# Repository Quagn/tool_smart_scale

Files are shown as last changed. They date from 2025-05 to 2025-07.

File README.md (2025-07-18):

# Smart Weight Scale - Cân Thông Minh Đo Trọng Tâm

## Giới thiệu

Dự án thiết kế và xây dựng thiết bị cân thông minh có khả năng:
- Đo trọng lượng chính xác với 6 cảm biến load cell
- Tính toán trọng tâm 2D và 3D
- Hiển thị thông tin qua LCD và Web interface
- Cập nhật firmware OTA (Over-The-Air)

## Tính năng chính

### 1. Đo lường
- **Trọng lượng**: Tổng hợp từ 6 cảm biến load cell
- **Trọng tâm 2D**: Tính toán vị trí X, Y trên mặt phẳng
- **Trọng tâm 3D**: Sử dụng servo để nghiêng và tính toán độ cao Z
- **Hiệu chuẩn**: Tự động lưu và khôi phục từ EEPROM

### 2. Giao diện
- **LCD 16x2**: Hiển thị trọng lượng, trọng tâm, menu
- **Web Interface**: Theo dõi real-time qua WebSocket
- **API RESTful**: Tích hợp với các hệ thống khác

### 3. Điều khiển
- **2 nút bấm**: Đa chức năng (click, double-click, long press)
- **Menu hệ thống**: Điều hướng các chức năng
- **Chế độ OTA**: Cập nhật firmware qua WiFi

## Kiến trúc Hệ thống

### Sơ đồ Tổng quan

```mermaid
graph TB
    subgraph "Hardware Layer"
        HW1["6x Load Cell"]
        HW2["3x HX711 ADC"]
        HW3["LCD 16x2 I2C"]
        HW4["2x Push Button"]
        HW5["1x Servo Motor"]
        HW6["Battery Monitor"]
        HW7["ESP8266 (NodeMCU)"]
    end
    
    subgraph "Driver Layer"
        DRV1["LoadCellArray"]
        DRV2["Display"]
        DRV3["ButtonManager"]
        DRV4["ServoController"]
        DRV5["BatteryMonitor"]
    end
    
    subgraph "Application Layer"
        APP1["StateMachine"]
        APP2["Main Loop"]
        APP3["Event Handlers"]
    end
    
    subgraph "Service Layer"
        SRV1["WebServer"]
        SRV2["WebSocket"]
        SRV3["OTA Service"]
        SRV4["WiFi Manager"]
    end
    
    subgraph "External Interface"
        EXT1["Web Browser"]
        EXT2["Mobile App"]
        EXT3["REST API Clients"]
    end
    
    HW1 --> HW2
    HW2 --> DRV1
    HW3 --> DRV2
    HW4 --> DRV3
    HW5 --> DRV4
    HW6 --> DRV5
    
    DRV1 --> APP2
    DRV2 --> APP2
    DRV3 --> APP3
    DRV4 --> APP2
    DRV5 --> APP2
    
    APP3 --> APP1
    APP1 --> APP2
    
    APP2 --> SRV1
    APP2 --> SRV2
    SRV3 --> HW7
    SRV4 --> HW7
    
    SRV1 --> EXT1
    SRV2 --> EXT1
    SRV1 --> EXT2
    SRV1 --> EXT3
```

## Trình tự Hoạt động Chi tiết

### 1. Quy trình Khởi động (Setup Flow)

```mermaid
flowchart TD
    A[Start] --> B["Initialize Serial (115200 baud)"]
    B --> C[setupHardware]
    
    C --> C1["Init Display - Show Booting..."]
    C1 --> C2["Init Buttons - Set callbacks"]
    C2 --> C3["Init Battery Monitor"]
    C3 --> C4["Init Servo"]
    C4 --> C5["Init State Machine"]
    
    C5 --> D{"Button 1 Pressed?"}
    D -->|Yes| E["Set OTA Mode - Display OTA Mode"]
    D -->|No| F["Normal Mode"]
    
    E --> G[setupNetwork]
    F --> G
    
    G --> G1["Try WiFi Connection (STA Mode)"]
    G1 --> G2{"Connected?"}
    G2 -->|Yes| G3["Display IP Address - Start mDNS"]
    G2 -->|No| G4["Start AP Mode - Display AP IP"]
    
    G3 --> H[setupWebServer]
    G4 --> H
    
    H --> H1["Setup WebSocket (/ws)"]
    H1 --> H2["Setup API Endpoints"]
    H2 --> H3["Setup Web UI (Root page)"]
    H3 --> H4["Start HTTP Server (Port 80)"]
    
    H4 --> I{"OTA Mode?"}
    I -->|Yes| J["setupOTA (Elegant OTA)"]
    I -->|No| K["Init Load Cells"]
    
    J --> L["Enter Main Loop"]
    
    K --> K1{"Load Cells Init OK?"}
    K1 -->|Yes| K2["Send INIT_COMPLETE - Set DISPLAY_WEIGHT"]
    K1 -->|No| K3["Display Error - Send ERROR Event"]
    
    K2 --> L
    K3 --> L
```

#### Chi tiết các bước khởi động:

1. **Khởi tạo Serial**: Baud rate 115200 cho debug
2. **setupHardware()**: 
   - Khởi tạo LCD và hiển thị "Booting..."
   - Cấu hình 2 nút bấm với callback functions
   - Khởi động battery monitor
   - Khởi tạo servo ở vị trí trung tâm
   - Khởi động state machine ở trạng thái BOOT

3. **Kiểm tra chế độ OTA**: Nếu Button 1 được giữ lúc khởi động
4. **setupNetwork()**:
   - Thử kết nối WiFi với credentials đã lưu
   - Nếu thành công: Hiển thị IP, bật mDNS
   - Nếu thất bại: Chuyển sang AP mode

5. **setupWebServer()**:
   - Cấu hình WebSocket endpoint `/ws`
   - Thiết lập các API: `/api/weight`, `/api/center`, `/api/battery`, etc.
   - Tạo trang web đơn giản cho monitoring
   - Khởi động HTTP server trên port 80

6. **Khởi tạo Load Cells** (nếu không phải OTA mode):
   - Khởi tạo 3 HX711 với 6 load cell
   - Load calibration từ EEPROM
   - Kiểm tra kết nối và tính ổn định

### 2. Vòng lặp chính (Main Loop)

```mermaid
flowchart TD
    A["Main Loop Start"] --> B["Update State Machine"]
    B --> C["Update Hardware"]
    
    C --> C1["Update Buttons"]
    C1 --> C2["Update Battery"]
    C2 --> C3{"OTA Mode?"}
    
    C3 -->|No| C4["Update Load Cells"]
    C3 -->|Yes| D["Update WebSocket"]
    
    C4 --> C5["Update Servo"]
    C5 --> C6["Update Display"]
    C6 --> C7["Handle Button Events"]
    
    C7 --> C8{"Current State?"}
    
    C8 -->|IDLE/MEASURING| C9["Display Weight Data"]
    C8 -->|CENTER_GRAVITY_2D/3D| C10["Display Center of Gravity"]
    C8 -->|MENU| C11["Display Menu"]
    C8 -->|Other| D
    
    C9 --> D
    C10 --> D
    C11 --> D
    
    D --> D1["Check WiFi Status"]
    D1 --> D2{"WiFi Connected?"}
    
    D2 -->|Connected & was disconnected| D3["Send NETWORK_CONNECTED event"]
    D2 -->|Disconnected & was connected| D4["Send NETWORK_DISCONNECTED event"]
    D2 -->|No change| D5["Check Battery"]
    
    D3 --> D5
    D4 --> D5
    
    D5 --> D6{"Low Battery?"}
    D6 -->|Yes| D7["Send LOW_BATTERY event"]
    D6 -->|No| A
    
    D7 --> A
```

#### Chi tiết vòng lặp chính:

1. **Update State Machine**: Xử lý events và state transitions
2. **Update Hardware**: 
   - Đọc trạng thái buttons (debouncing, multi-click detection)
   - Đo điện áp pin (moving average filter)
   - Đọc 6 load cell (non-blocking)
   - Cập nhật vị trí servo (smooth movement)
   - Refresh LCD display (rate limited)

3. **Display Logic**: Dựa trên state hiện tại:
   - **IDLE/MEASURING**: Hiển thị tổng trọng lượng + status các cell
   - **CENTER_GRAVITY**: Hiển thị tọa độ X, Y (và Z nếu 3D)
   - **MENU**: Hiển thị menu items và navigation

4. **WebSocket Updates**: Gửi real-time data tới web clients
5. **Network Monitoring**: Tự động reconnect WiFi nếu mất kết nối
6. **Battery Management**: Cảnh báo pin yếu

### 3. Xử lý Sự kiện Nút bấm

```mermaid
flowchart TD
    A["Button Event"] --> B{"Which Button?"}
    
    B -->|Button 1 Click| C["Send BUTTON1_CLICK event"]
    B -->|Button 1 Long Press| D["Send BUTTON1_LONG event"]
    B -->|Button 2 Click| E["Send BUTTON2_CLICK event"]
    B -->|Button 2 Long Press| F["Send BUTTON2_LONG event"]
    B -->|Both Buttons| G["Send BOTH_BUTTONS event"]
    
    C --> C1{"Current State?"}
    C1 -->|IDLE| C2["Send MEASURE_START event"]
    C1 -->|MENU| C3["Navigate Menu (menuNext)"]
    
    D --> D1{"Current State?"}
    D1 -->|IDLE| D2["Force transition to MENU"]
    
    E --> E1{"Current State?"}
    E1 -->|IDLE| E2["Execute Tare - Send TARE_COMPLETE"]
    E1 -->|MENU| E3["Send MENU_SELECT event"]
    
    F --> F1{"Current State?"}
    F1 -->|Not IDLE| F2["Send MENU_EXIT event"]
    
    G --> G1["Emergency Restart (ESP.restart)"]
    
    C2 --> H["Return to Loop"]
    C3 --> H
    D2 --> H
    E2 --> H
    E3 --> H
    F2 --> H
    G1 --> I["System Restart"]
```

#### Chức năng nút bấm chi tiết:

**Button 1 (Primary):**
- **Single Click**: 
  - Ở IDLE: Bắt đầu đo lường
  - Ở MENU: Chuyển đến item tiếp theo
- **Long Press**: Vào menu hệ thống
- **Double Click**: Chuyển chế độ hiển thị (weight ↔ center of gravity)

**Button 2 (Secondary):**
- **Single Click**:
  - Ở IDLE: Thực hiện Tare (zero offset)
  - Ở MENU: Chọn menu item hiện tại
- **Long Press**: Thoát khỏi menu/chế độ hiện tại
- **Double Click**: Hiển thị thông tin hệ thống

**Both Buttons**: Emergency restart

### 4. State Machine

```mermaid
stateDiagram-v2
    [*] --> BOOT : System Start
    
    BOOT --> OTA_MODE : Button 1 held at boot
    BOOT --> INIT : Normal boot
    
    OTA_MODE --> [*] : OTA Update Complete
    
    INIT --> IDLE : INIT_COMPLETE event
    INIT --> ERROR : Initialization failed
    
    IDLE --> MEASURING : MEASURE_START / Button 1 click
    IDLE --> MENU : BUTTON1_LONG
    IDLE --> IDLE : TARE_COMPLETE / Button 2 click
    IDLE --> LOW_BATTERY : Low battery detected
    IDLE --> ERROR : System error
    
    MEASURING --> IDLE : MEASURE_COMPLETE / Timeout
    MEASURING --> IDLE : BUTTON2_LONG (exit)
    MEASURING --> CENTER_GRAVITY_2D : User selection
    
    CENTER_GRAVITY_2D --> CENTER_GRAVITY_3D : 3D measurement request
    CENTER_GRAVITY_2D --> IDLE : BUTTON2_LONG (exit)
    
    CENTER_GRAVITY_3D --> CENTER_GRAVITY_2D : Measurement complete
    CENTER_GRAVITY_3D --> IDLE : BUTTON2_LONG (exit)
    
    MENU --> IDLE : MENU_EXIT / BUTTON2_LONG
    MENU --> CALIBRATION : Menu selection (Calibrate)
    MENU --> TARE : Menu selection (Tare)
    MENU --> NETWORK_CONFIG : Menu selection (Network)
    
    CALIBRATION --> IDLE : Calibration complete
    CALIBRATION --> IDLE : BUTTON2_LONG (cancel)
    
    TARE --> IDLE : TARE_COMPLETE
    
    NETWORK_CONFIG --> IDLE : Configuration complete
    NETWORK_CONFIG --> IDLE : BUTTON2_LONG (cancel)
    
    ERROR --> IDLE : BUTTON1_CLICK / BUTTON2_CLICK (acknowledge)
    
    LOW_BATTERY --> IDLE : Battery level restored
    LOW_BATTERY --> [*] : Auto shutdown
```

#### Mô tả các trạng thái:

- **BOOT**: Khởi động hệ thống
- **OTA_MODE**: Chế độ cập nhật firmware
- **INIT**: Khởi tạo phần cứng
- **IDLE**: Trạng thái chờ, hiển thị trọng lượng
- **MEASURING**: Đang đo lường chính xác
- **CENTER_GRAVITY_2D**: Hiển thị trọng tâm 2D
- **CENTER_GRAVITY_3D**: Đo trọng tâm 3D (với servo)
- **MENU**: Hiển thị menu hệ thống
- **CALIBRATION**: Hiệu chuẩn cảm biến
- **TARE**: Thực hiện cân bằng không
- **NETWORK_CONFIG**: Cấu hình WiFi
- **ERROR**: Trạng thái lỗi
- **LOW_BATTERY**: Cảnh báo pin yếu

## Phần cứng

### Linh kiện chính
- **MCU**: ESP8266 (NodeMCU v2)
- **Cảm biến**: 6x Load cell + 3x HX711 (dual channel)
- **Hiển thị**: LCD 16x2 I2C
- **Cơ khí**: 1x Servo (cho đo 3D)
- **Nguồn**: Pin Li-ion với mạch giám sát điện áp

### Sơ đồ kết nối
```
ESP8266 GPIO    Thiết bị
D6 (GPIO12) --> HX711_1 DOUT
D7 (GPIO13) --> HX711_1 SCK
D5 (GPIO14) --> HX711_2 DOUT
D2 (GPIO4)  --> HX711_2 SCK
D1 (GPIO5)  --> HX711_3 DOUT
D0 (GPIO16) --> HX711_3 SCK
D4 (GPIO2)  --> LCD SDA (I2C)
D3 (GPIO0)  --> LCD SCL (I2C)
D8 (GPIO15) --> Button 1
RX (GPIO3)  --> Button 2
TX (GPIO1)  --> Servo
A0         --> Battery voltage (với voltage divider)
```

## Phần mềm

### Cấu trúc thư mục
```
src/
├── main.cpp           # Chương trình chính
├── config/            # File cấu hình
│   ├── PinConfig.h
│   ├── SystemConfig.h
│   └── WebConfig.h
├── drivers/           # Driver phần cứng
│   ├── LoadCellArray.*
│   ├── Display.*
│   ├── ButtonManager.*
│   ├── ServoController.*
│   └── BatteryMonitor.*
├── services/          # Dịch vụ hệ thống
│   └── ...
├── app/              # Logic ứng dụng
│   └── StateMachine.*
└── utils/            # Tiện ích
    └── ...
```

## Cài đặt và Sử dụng

### 1. Yêu cầu
- PlatformIO IDE (VSCode extension recommended)
- ESP8266 board package
- Các thư viện (tự động cài qua PlatformIO):
  - HX711_ADC
  - LiquidCrystal_I2C
  - ESPAsyncWebServer
  - AsyncElegantOTA
  - ArduinoJson

### 2. Cấu hình
1. Sửa WiFi credentials trong `src/config/WebConfig.h`
2. Điều chỉnh vị trí cảm biến trong `src/config/SystemConfig.h`
3. Kiểm tra pin configuration trong `src/config/PinConfig.h`

### 3. Biên dịch và nạp
```bash
# Build
pio run

# Upload qua USB
pio run --target upload

# Upload OTA (sau lần đầu)
pio run --target upload --upload-port smartscale.local
```

### 4. Sử dụng

#### Khởi động thường:
1. Bật nguồn → Hệ thống tự động kết nối WiFi
2. LCD hiển thị trọng lượng
3. Truy cập web: http://smartscale.local

#### Chế độ OTA:
1. Giữ Button 1 khi khởi động
2. Kết nối WiFi AP: "SmartScale_AP" 
3. Truy cập: http://192.168.4.1/update
4. Upload file firmware.bin

#### Điều khiển nút bấm:
- **Button 1**: Click = Đo | Long = Menu
- **Button 2**: Click = Tare | Long = Thoát
- **Both**: Khởi động lại

## API Endpoints

| Method | Endpoint | Mô tả |
|---|---|---|
| GET | /api/weight | Lấy trọng lượng hiện tại |
| GET | /api/center | Lấy tọa độ trọng tâm |
| GET | /api/battery | Trạng thái pin |
| POST | /api/tare | Thực hiện tare |
| POST | /api/calibrate | Bắt đầu hiệu chuẩn |
| POST | /api/restart | Khởi động lại |

## WebSocket

Kết nối: `ws://smartscale.local/ws`

Dữ liệu (JSON):
```json
{
  "weight": 1234.5,
  "battery": 85,
  "centerX": 10.2,
  "centerY": -5.8
}
```

## Thuật toán Tính Toán

### Trọng tâm 2D
```
X = Σ(Wi × Xi) / ΣWi
Y = Σ(Wi × Yi) / ΣWi

Trong đó:
- Wi: Trọng lượng tại cảm biến i
- Xi, Yi: Tọa độ cảm biến i (mm)
```

### Vị trí 6 cảm biến (bố trí hình tròn, bán kính 150mm):
- LoadCell 0: 0° → (150, 0)
- LoadCell 1: 60° → (75, 129.9)
- LoadCell 2: 120° → (-75, 129.9)
- LoadCell 3: 180° → (-150, 0)
- LoadCell 4: 240° → (-75, -129.9)
- LoadCell 5: 300° → (75, -129.9)

### Trọng tâm 3D
1. Đo ở vị trí nằm ngang → Tính X₀, Y₀
2. Nghiêng cân α° bằng servo → Đo lại → Tính X₁, Y₁
3. Tính Z: `Z = (X₁ - X₀) / tan(α)`

## Hiệu chuẩn

### Quy trình tự động:
1. Vào menu Calibration
2. Đặt cân về 0 → Nhấn Tare
3. Đặt quả cân chuẩn lên từng vị trí
4. Nhập khối lượng chuẩn
5. Hệ thống tự động tính toán và lưu vào EEPROM

### Hiệu chuẩn thủ công qua Web API:
```bash
# Tare all cells
curl -X POST http://smartscale.local/api/tare

# Calibrate specific cell
curl -X POST http://smartscale.local/api/calibrate \
  -d '{"cell": 0, "weight": 1000}' \
  -H "Content-Type: application/json"
```

## Khắc phục sự cố

| Vấn đề | Triệu chứng | Giải pháp |
|---|---|---|
| Không kết nối WiFi | LCD hiển thị AP mode | Kiểm tra SSID/Password, reset về AP mode |
| Load cell không ổn định | Số liệu nhảy liên tục | Kiểm tra kết nối, thực hiện tare, kiểm tra nhiễu |
| LCD không hiển thị | Màn hình trống | Kiểm tra I2C address (mặc định 0x27), kết nối SDA/SCL |
| OTA thất bại | Upload bị lỗi | Kiểm tra dung lượng flash còn trống, network stability |
| Servo không hoạt động | Không nghiêng khi đo 3D | Kiểm tra nguồn servo, kết nối PWM |
| Pin cạn nhanh | Cảnh báo low battery | Kiểm tra voltage divider, tối ưu power management |

## Monitoring và Debug

### Serial Monitor (115200 baud):
```
=== Smart Weight Scale ===
Firmware Version: 1.0.0
Display initialized
ButtonManager initialized
Battery: 4.12V (98%)
LoadCell Array initialized
WiFi connected! IP: 192.168.1.100
Web server started
State transition: BOOT -> IDLE
```

### Web Debug Interface:
- Truy cập: `http://smartscale.local/debug`
- Hiển thị raw data từ tất cả sensors
- Log events và state transitions
- Performance metrics

## Đóng góp

Mọi đóng góp đều được chào đón! Vui lòng:
1. Fork repository
2. Tạo branch mới cho tính năng
3. Commit và push
4. Tạo Pull Request

### Coding Standards:
- Sử dụng camelCase cho variables/functions
- PascalCase cho classes
- UPPER_CASE cho constants
- Comment code bằng tiếng Việt hoặc tiếng Anh
- Follow Arduino coding style

## License

MIT License - Xem file LICENSE để biết thêm chi tiết.

## Changelog

### v1.0.0 (2024-07-16)
- Initial release
- Basic weight measurement
- 2D center of gravity calculation
- Web interface with WebSocket
- OTA update support

### Planned Features:
- [ ] 3D center of gravity với servo
- [ ] Data logging to SPIFFS/SD card
- [ ] Mobile app (React Native)
- [ ] Cloud integration (MQTT/HTTP)
- [ ] Multiple user profiles
- [ ] Advanced calibration wizard

## Tác giả

[Your Name] - [your.email@example.com]

## Lời cảm ơn

- Thư viện HX711 của bogde
- ESPAsyncWebServer của me-no-dev
- AsyncElegantOTA của ayushsharma82
- Cộng đồng Arduino và ESP8266

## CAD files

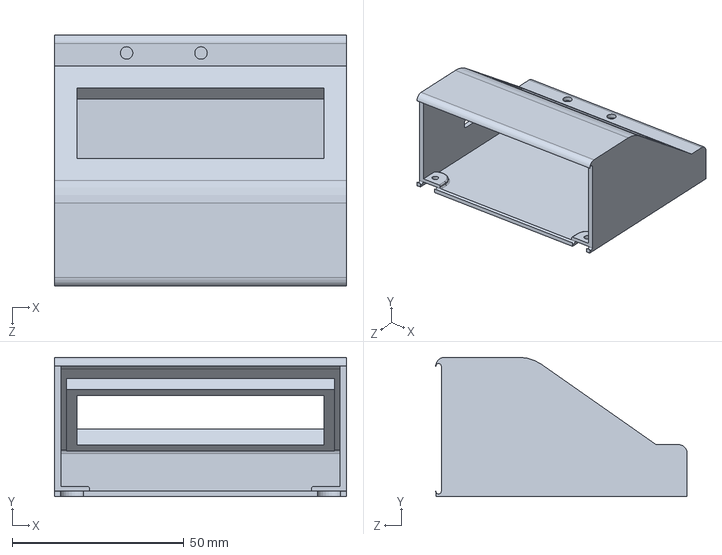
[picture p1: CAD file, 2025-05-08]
hardware/Hop_mach_dieu_khien.SLDPRT
85.0 x 40.6 x 73.2 mm

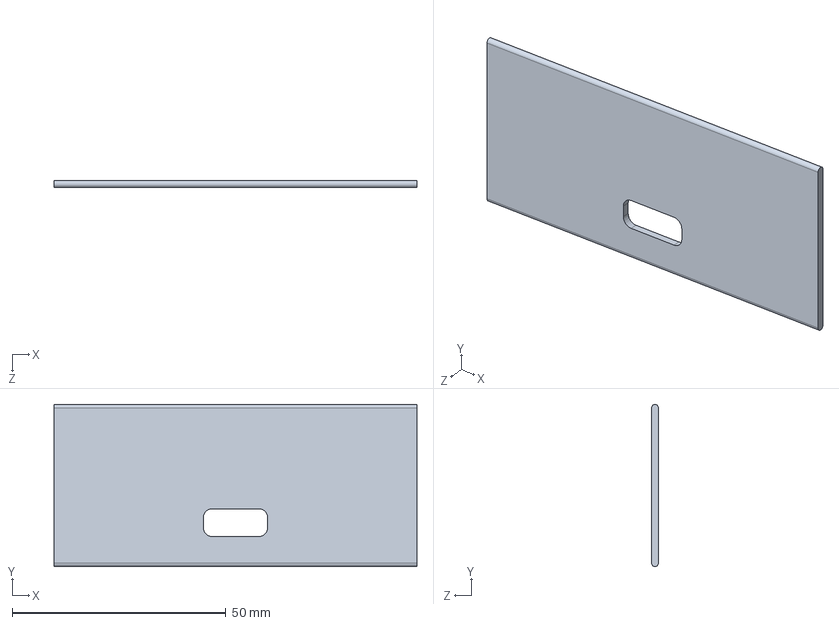
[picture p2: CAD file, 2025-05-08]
hardware/Hop_mach_dieu_khien_nap.SLDPRT
85.0 x 38.0 x 1.60 mm

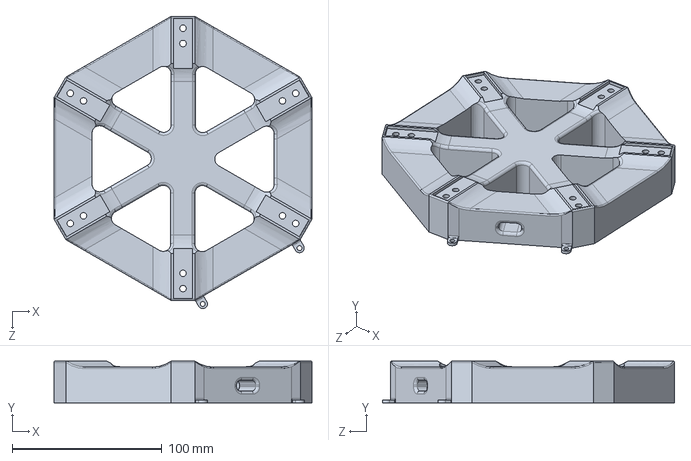
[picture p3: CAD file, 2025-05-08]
hardware/De_Giu.SLDPRT
172.5 x 28.0 x 195.5 mm

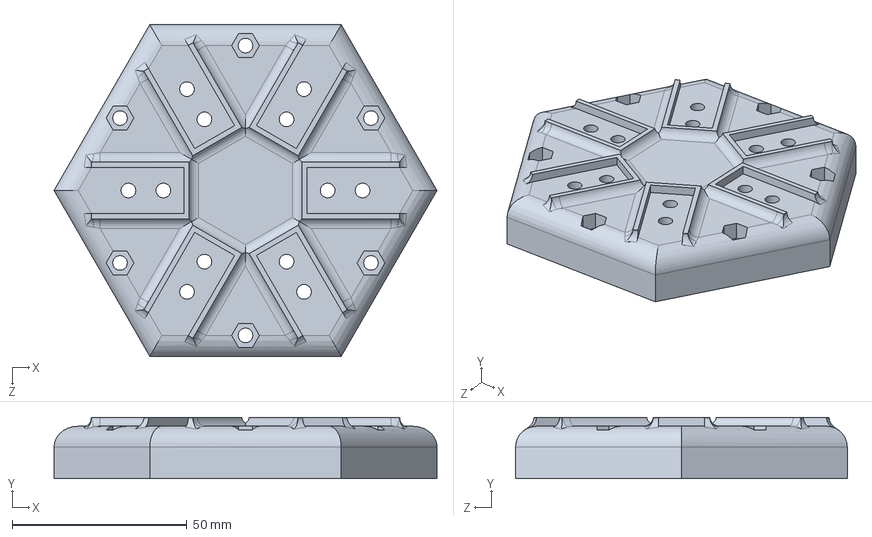
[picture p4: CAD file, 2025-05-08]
hardware/De_tren.SLDPRT
109.7 x 17.5 x 95.0 mm

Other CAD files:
hardware/De_Giu.STL
hardware/De_tren.STL
hardware/Hop_mach_dieu_khien.STL
hardware/Hop_mach_dieu_khien_nap.STL

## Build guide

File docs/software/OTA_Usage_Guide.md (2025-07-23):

# OTA (Over-The-Air) Update Guide

## Overview

The Smart Weight Scale supports wireless firmware updates through OTA (Over-The-Air) functionality. This guide explains how to use this feature.

## How OTA Works

The OTA system in the Smart Weight Scale works as follows:

1. When triggered, the device will first attempt to connect to a known WiFi network (STA mode) for 20 seconds
2. If connection fails, it will create its own WiFi access point (AP mode)
3. The user connects to the device's web interface to upload new firmware
4. After successful update, the device will automatically restart with the new firmware

## Activating OTA Mode

OTA mode can be activated by:

1. Holding the designated button for 5 seconds (BUTTON_OTA_HOLD_TIME)
2. Calling the `ota_start()` function from your code

## Connecting to OTA

### If device connects to your WiFi (STA mode):

1. The device will connect to the configured WiFi network (WIFI_STA_SSID)
2. Look for the device's IP address in your router's connected devices list or in the serial monitor
3. Open a web browser and navigate to: `http://<device-ip>/update`

### If device creates its own WiFi (AP mode):

1. Connect your computer or mobile device to the WiFi network named `SmartScale_OTA`
2. Password: `ota123456`
3. Open a web browser and navigate to: `http://192.168.4.1/update`

## Uploading Firmware

1. In the web interface, click "Choose File" to select your compiled firmware (.bin file)
2. Click "Update" to begin the upload process
3. Wait for the upload to complete (do not disconnect during this process)
4. The device will automatically restart with the new firmware

## Timeout

The OTA mode will automatically exit after 5 minutes (OTA_TIMEOUT_MS) if no update is performed.

## Code Example

```cpp
// Example of triggering OTA mode from your code
void enterOtaMode() {
    // Save any important data before entering OTA mode
    saveSettings();
  
    // Start OTA mode
    ota_start();
  
    // Main loop during OTA mode
    while (true) {
        ota_handle();  // Must be called regularly to handle OTA operations
        delay(10);
    }
}
```

## Customizing OTA Settings

You can customize OTA settings in the following files:

1. `src/config/peripheral_config.h` - WiFi credentials, timeout settings
2. `src/config/web_config.h` - Web server configuration
3. `src/service/ota/ota_handle.h` - OTA function declarations

## Troubleshooting

1. **Cannot connect to device in AP mode**

   - Make sure you're connecting to the correct WiFi network (SmartScale_OTA)
   - Try restarting the device and activating OTA mode again
2. **Upload fails**

   - Ensure you're uploading a valid firmware file (.bin)
   - Check that the file size is not too large for the device
   - Try reconnecting to the WiFi network and uploading again
3. **Device not responding after update**

   - If the device doesn't restart properly after an update, try manually resetting it
   - If issues persist, you may need to use serial programming to restore firmware

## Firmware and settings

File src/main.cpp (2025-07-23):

/*
Auth: Quang Minh
Date: 18/07/2025
*/
//----------------------------------------------------------------------------------// INCLUDES
#include <Arduino.h>                                                        // Arduino core library

#include "config/peripheral_config.h"                                       // Config peripheral
#include "config/service_config.h"                                          // Config service
#include "config/sys_core_config.h"                                         // Config system core
#include "config/sys_app_config.h"                                          // Config system app

#include "peripheral/int/init.h"                                            // Init peripheral
#include "peripheral/ext/button/button.h"                                   // Button
#include "peripheral/ext/battery/battery.h"                                 // Battery
#include "peripheral/ext/servo/servo.h"                                     // Servo

#include "service/power_manager.h"                                          // Power manager
#include "service/wifi_handle.h"                                            // Wifi manager
#include "service/ota/ota_handle.h"                                         // OTA handler

#include "application/event_handle.h"                                       // Event handler
#include "application/state_machine.h"                                      // State machine

//----------------------------------------------------------------------------------// Global variables


//----------------------------------------------------------------------------------// TypeDef
button_t button1;
button_t button2;
servo_t servo;
battery_t battery;

//----------------------------------------------------------------------------------// SETUP
void setup() {   
    power_init();                                                           // Internal peripherals init
    GPIO_Init();   
    I2C_Init();
    UART_Init();
    // ADC_Init();
    // PWM_Init();
    Serial.println("Internal peripherals initialized");

    button_init(&button1, BUTTON_1_PIN, BUTTON_ACTIVE_LOW);                 // External peripherals init
    button_init(&button2, BUTTON_2_PIN, BUTTON_ACTIVE_LOW);
    battery_init(&battery, BATTERY_ADC_PIN);
    servo_init(&servo, SERVO_PIN);
    Serial.println("External peripherals initialized");

    Wifi_Init();
    
    Serial.println("Checking if we should enter OTA mode...");
    // Check if we should enter OTA mode
    //if (button_check_ota_mode_entry(&button1, BUTTON_OTA_HOLD_TIME)) 
    if (true) 
    {
        ota_init();
        ota_start();
        ota_loop();
    } else {
        // Only initialize WiFi in normal mode
        Serial.println("Smart Weight Scale ready!");
    }
}

//----------------------------------------------------------------------------------// LOOP
void loop() {
    // Web handle
    button_update(&button1);
    button_update(&button2);
    
}

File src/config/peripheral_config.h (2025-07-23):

#ifndef PERIPHERAL_CONFIG_H
#define PERIPHERAL_CONFIG_H

//----------------------------------------------------------------------------------// Pin Mapping
// HX711 Load Cell Amplifiers
#define HX711_1_DOUT_PIN        12              // D6 - HX711 #1 Data
#define HX711_1_SCK_PIN         13              // D7 - HX711 #1 Clock

#define HX711_2_DOUT_PIN        14              // D5 - HX711 #2 Data  
#define HX711_2_SCK_PIN         4               // D2 - HX711 #2 Clock

#define HX711_3_DOUT_PIN        5               // D1 - HX711 #3 Data
#define HX711_3_SCK_PIN         16              // D0 - HX711 #3 Clock

// I2C for LCD Display
#define LCD_I2C_SDA_PIN         4               // D4 - I2C SDA
#define LCD_I2C_SCL_PIN         5               // D3 - I2C SCL

// Buttons
#define BUTTON_1_PIN            15              // D8 - Button 1 (with external pull-up)
#define BUTTON_2_PIN            3               // RX - Button 2 (use with caution)

// Servo
#define SERVO_PIN               1               // TX - Servo control (use with caution)

// Battery voltage monitoring
#define BATTERY_ADC_PIN         A0              // Analog input

// LED indicator (optional - using built-in LED)
#define LED_PIN                 LED_BUILTIN

//----------------------------------------------------------------------------------// Internal Peripherals
// ----- UART Configuration -----
#define UART0_BAUDRATE              115200
                                                                
// ----- SPI Configuration -----
// #define SPI_FREQUENCY               1000000  // 1MHz

// ----- I2C Configuration -----
#define I2C_FREQUENCY               100000      // 100kHz

// ----- PWM Configuration -----
#define SERVO_PWM_FREQ              50          // 50Hz
#define SERVO_PWM_RESOLUTION        1023        // 10-bit

// ----- ADC Configuration -----
#define ADC_RESOLUTION              10          // 10-bit

//----------------------------------------------------------------------------------// External Peripherals
// Battery
#define BATTERY_MIN_VOLTAGE     3.0f            // V - Minimum battery voltage
#define BATTERY_MAX_VOLTAGE     4.2f            // V - Maximum battery voltage
#define BATTERY_ADC_SAMPLES     5               // Number of samples for noise filtering
#define BATTERY_VOLTAGE_DIVIDER 2.0f            // Voltage divider ratio (if any)

// Button
#define BUTTON_DEBOUNCE_DELAY   50              // ms - Debounce delay
#define BUTTON_LONG_PRESS_TIME  1000            // ms - Long press time
#define BUTTON_OTA_HOLD_TIME    5000            // ms - Hold time to enter OTA mode
#define BUTTON_ACTIVE_LOW       true            // true if button active low

// Servo
#define SERVO_MIN_PULSE_WIDTH   544             // us - Minimum pulse width (0 degree)
#define SERVO_MAX_PULSE_WIDTH   2400            // us - Maximum pulse width (180 degree)
#define SERVO_REFRESH_INTERVAL  20000           // us - PWM refresh interval (50Hz)
#define SERVO_MIN_ANGLE         0               // degree - Minimum angle
#define SERVO_MAX_ANGLE         180             // degree - Maximum angle

#endif // PERIPHERAL_CONFIG_H

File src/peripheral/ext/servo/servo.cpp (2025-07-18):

#include "servo.h"

void servo_init(servo_t* srv, uint8_t pin) {
    srv->pin = pin;
    srv->current_angle = 90;  // Góc mặc định ở giữa
    srv->target_angle = 90;
    srv->last_update_time = 0;
    srv->attached = false;
}

void servo_attach(servo_t* srv) {
    if (!srv->attached) {
        pinMode(srv->pin, OUTPUT);
        srv->attached = true;
        
        // Đặt servo về vị trí mặc định
        servo_write_angle(srv, srv->current_angle);
    }
}

void servo_detach(servo_t* srv) {
    if (srv->attached) {
        digitalWrite(srv->pin, LOW);
        srv->attached = false;
    }
}

void servo_write_angle(servo_t* srv, uint16_t angle) {
    if (!srv->attached) return;
    
    // Giới hạn góc trong khoảng cho phép
    if (angle > SERVO_MAX_ANGLE) {
        angle = SERVO_MAX_ANGLE;
    }
    
    // Chuyển đổi góc sang độ rộng xung
    uint16_t pulse_width = map(angle, SERVO_MIN_ANGLE, SERVO_MAX_ANGLE, 
                              SERVO_MIN_PULSE_WIDTH, SERVO_MAX_PULSE_WIDTH);
    
    servo_write_microseconds(srv, pulse_width);
    srv->current_angle = angle;
}

void servo_write_microseconds(servo_t* srv, uint16_t microseconds) {
    if (!srv->attached) return;
    
    // Giới hạn độ rộng xung
    if (microseconds < SERVO_MIN_PULSE_WIDTH) {
        microseconds = SERVO_MIN_PULSE_WIDTH;
    }
    if (microseconds > SERVO_MAX_PULSE_WIDTH) {
        microseconds = SERVO_MAX_PULSE_WIDTH;
    }
    
    // Tạo xung PWM thủ công
    digitalWrite(srv->pin, HIGH);
    delayMicroseconds(microseconds);
    digitalWrite(srv->pin, LOW);
    delayMicroseconds(SERVO_REFRESH_INTERVAL - microseconds);
}

uint16_t servo_read_angle(servo_t* srv) {
    return srv->current_angle;
}

bool servo_is_attached(servo_t* srv) {
    return srv->attached;
}

void servo_update(servo_t* srv) {
    if (!srv->attached) return;
    
    unsigned long current_time = millis();
    
    // Cập nhật vị trí servo mỗi 20ms (50Hz)
    if (current_time - srv->last_update_time >= 20) {
        if (srv->current_angle != srv->target_angle) {
            // Di chuyển từ từ về vị trí đích
            if (srv->current_angle < srv->target_angle) {
                srv->current_angle++;
            } else {
                srv->current_angle--;
            }
            
            servo_write_angle(srv, srv->current_angle);
        }
        
        srv->last_update_time = current_time;
    }
}

void servo_move_to(servo_t* srv, uint16_t target_angle, uint16_t speed) {
    if (!srv->attached) return;
    
    // Giới hạn góc đích
    if (target_angle > SERVO_MAX_ANGLE) {
        target_angle = SERVO_MAX_ANGLE;
    }
    
    srv->target_angle = target_angle;
    
    if (speed == 0) {
        // Di chuyển ngay lập tức
        servo_write_angle(srv, target_angle);
    } else {
        // Di chuyển từ từ - sẽ được xử lý trong servo_update()
        // Speed parameter có thể được sử dụng để điều chỉnh tốc độ trong tương lai
    }
} 
